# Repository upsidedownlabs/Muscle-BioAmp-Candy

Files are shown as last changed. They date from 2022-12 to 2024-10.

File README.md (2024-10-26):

# Muscle-BioAmp-Candy

 



[]() 
 


A candy size ElectroMyography (EMG) sensor for precise muscle bio-potential signals recording at an affordable cost. It comes with a fixed gain of x2420 and BandPass filter of 72Hz - 720Hz. To record the EMG signals you can use any standalone ADC like ADS1115 or any microcontroller development board with an ADC of your choice like Arduino UNO/Nano.

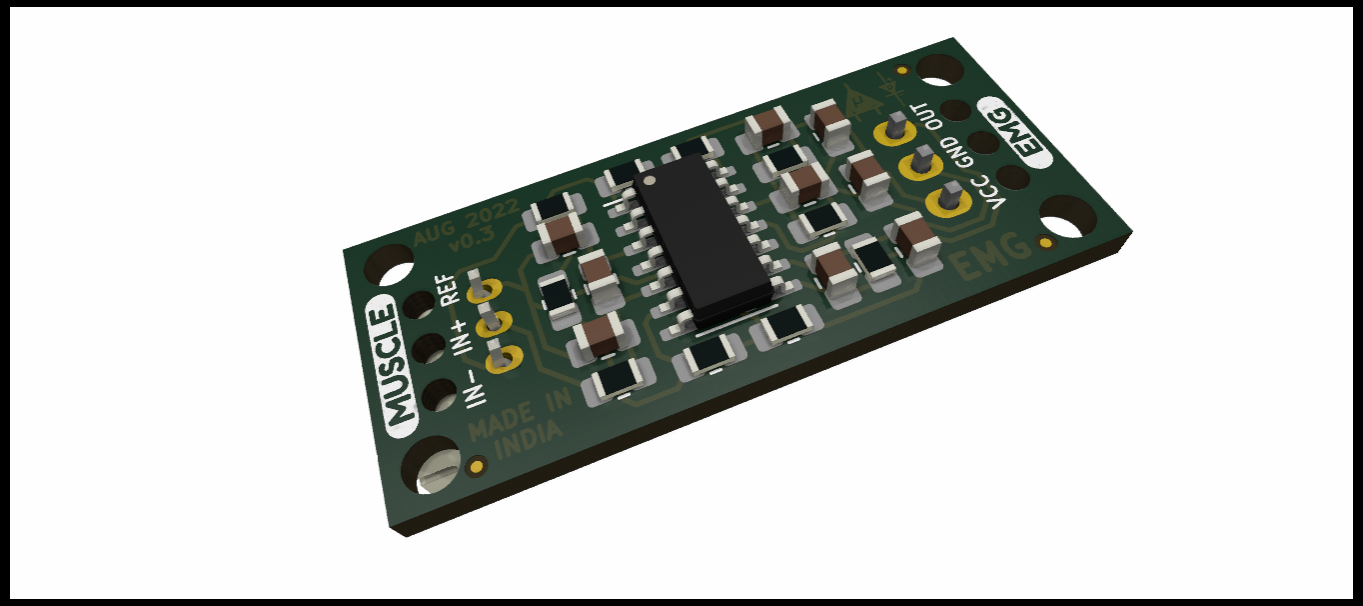
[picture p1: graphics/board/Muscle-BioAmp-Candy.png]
Upside Down Labs - Muscle BioAmp Candy


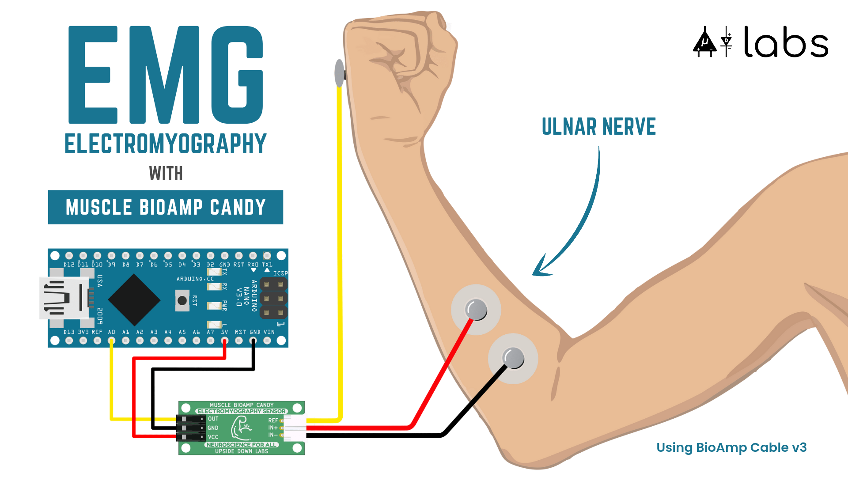
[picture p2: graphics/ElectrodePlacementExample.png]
Upside Down Labs - Muscle BioAmp Candy electrode placement


## Hardware

Muscle BioAmp Candy has been created using KiCad and all the design files can be found under [hardware](hardware/) folder. Images below shows a quick overview of the hardware design.

| PCB Front |  PCB Back |
| :---: | :---: |
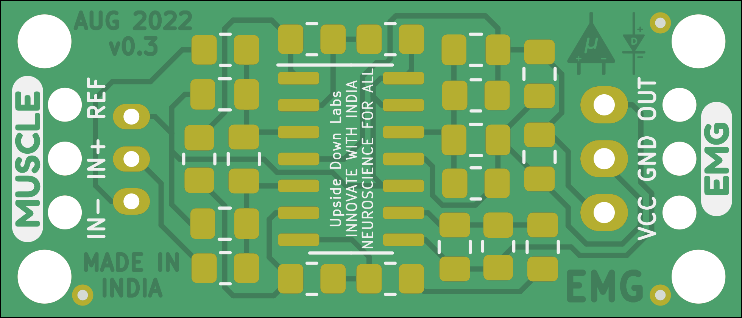
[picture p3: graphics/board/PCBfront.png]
Upside Down Labs Muscle BioAmp Candy front
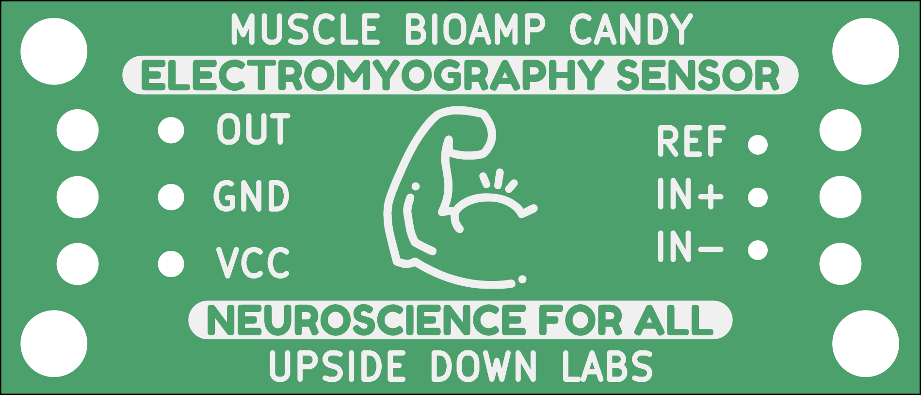
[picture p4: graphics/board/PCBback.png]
Upside Down Labs Muscle BioAmp Candy back
|   |  |

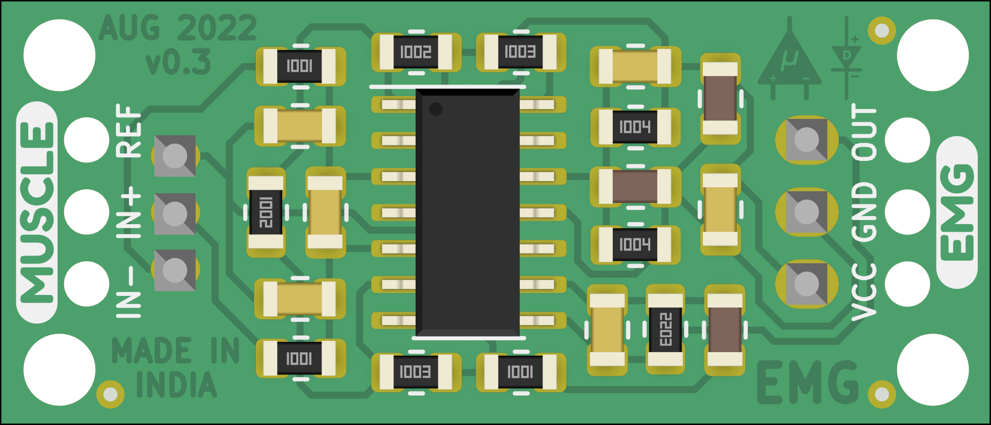
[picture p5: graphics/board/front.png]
Upside Down Labs Muscle BioAmp Candy front annotated


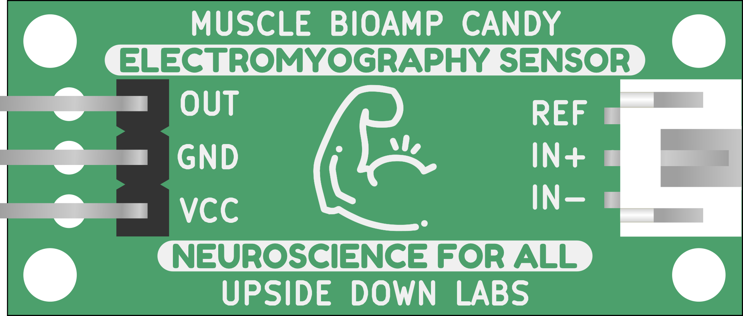
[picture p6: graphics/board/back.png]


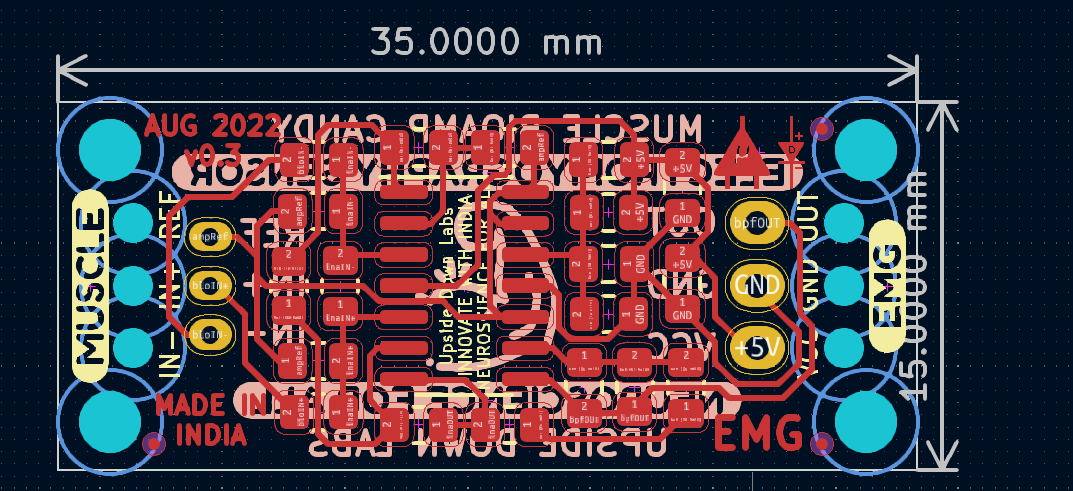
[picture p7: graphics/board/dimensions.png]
Upside Down Labs Muscle BioAmp Candy dimensions


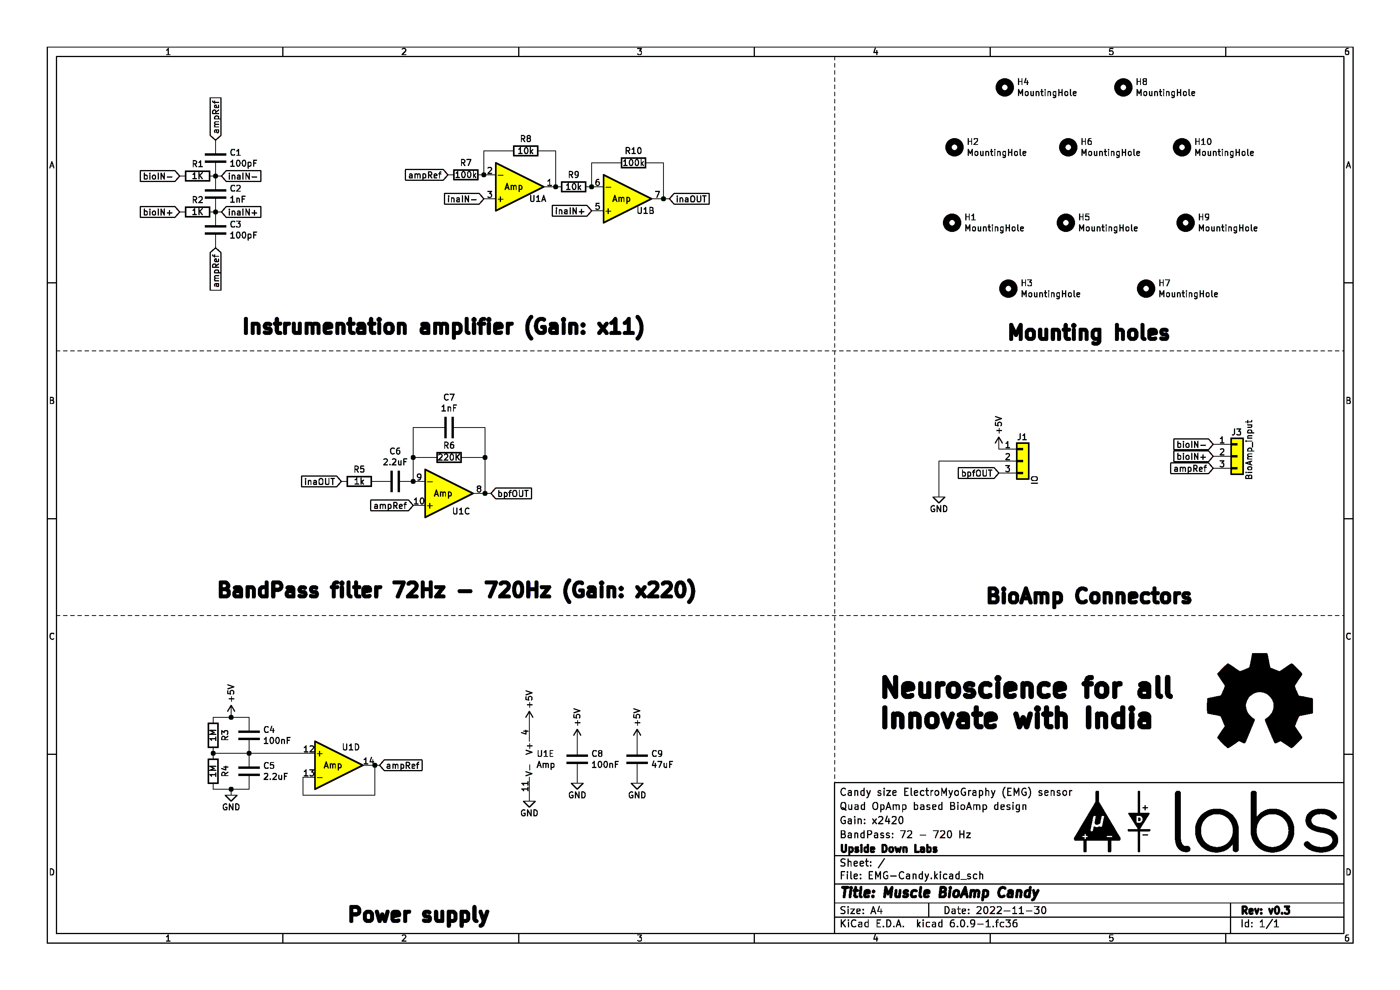
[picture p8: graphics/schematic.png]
Upside Down Labs Muscle BioAmp Candy schematic


## License

| Licenses Facts |  OSHWA Certification |
| :---: | :---: |
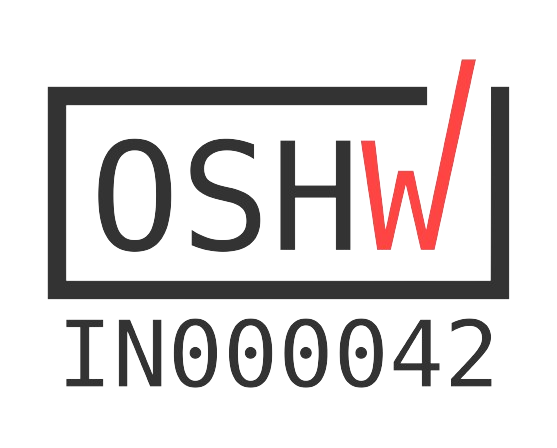
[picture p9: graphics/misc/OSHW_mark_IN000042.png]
Open Source Hardware Certification mark
| <a href="LICENSE.md">Open Source Licenses Facts</a>  |  | 

#### Hardware
CERN Open Hardware License Version 2 - Strongly Reciprocal ([CERN-OHL-S-2.0](https://spdx.org/licenses/CERN-OHL-S-2.0.html)).

#### Software
MIT open source [license](http://opensource.org/licenses/MIT).

#### Documentation:
<br />This work is licensed under a <a rel="license" href="http://creativecommons.org/licenses/by/4.0/">Creative Commons Attribution 4.0 International License</a>.

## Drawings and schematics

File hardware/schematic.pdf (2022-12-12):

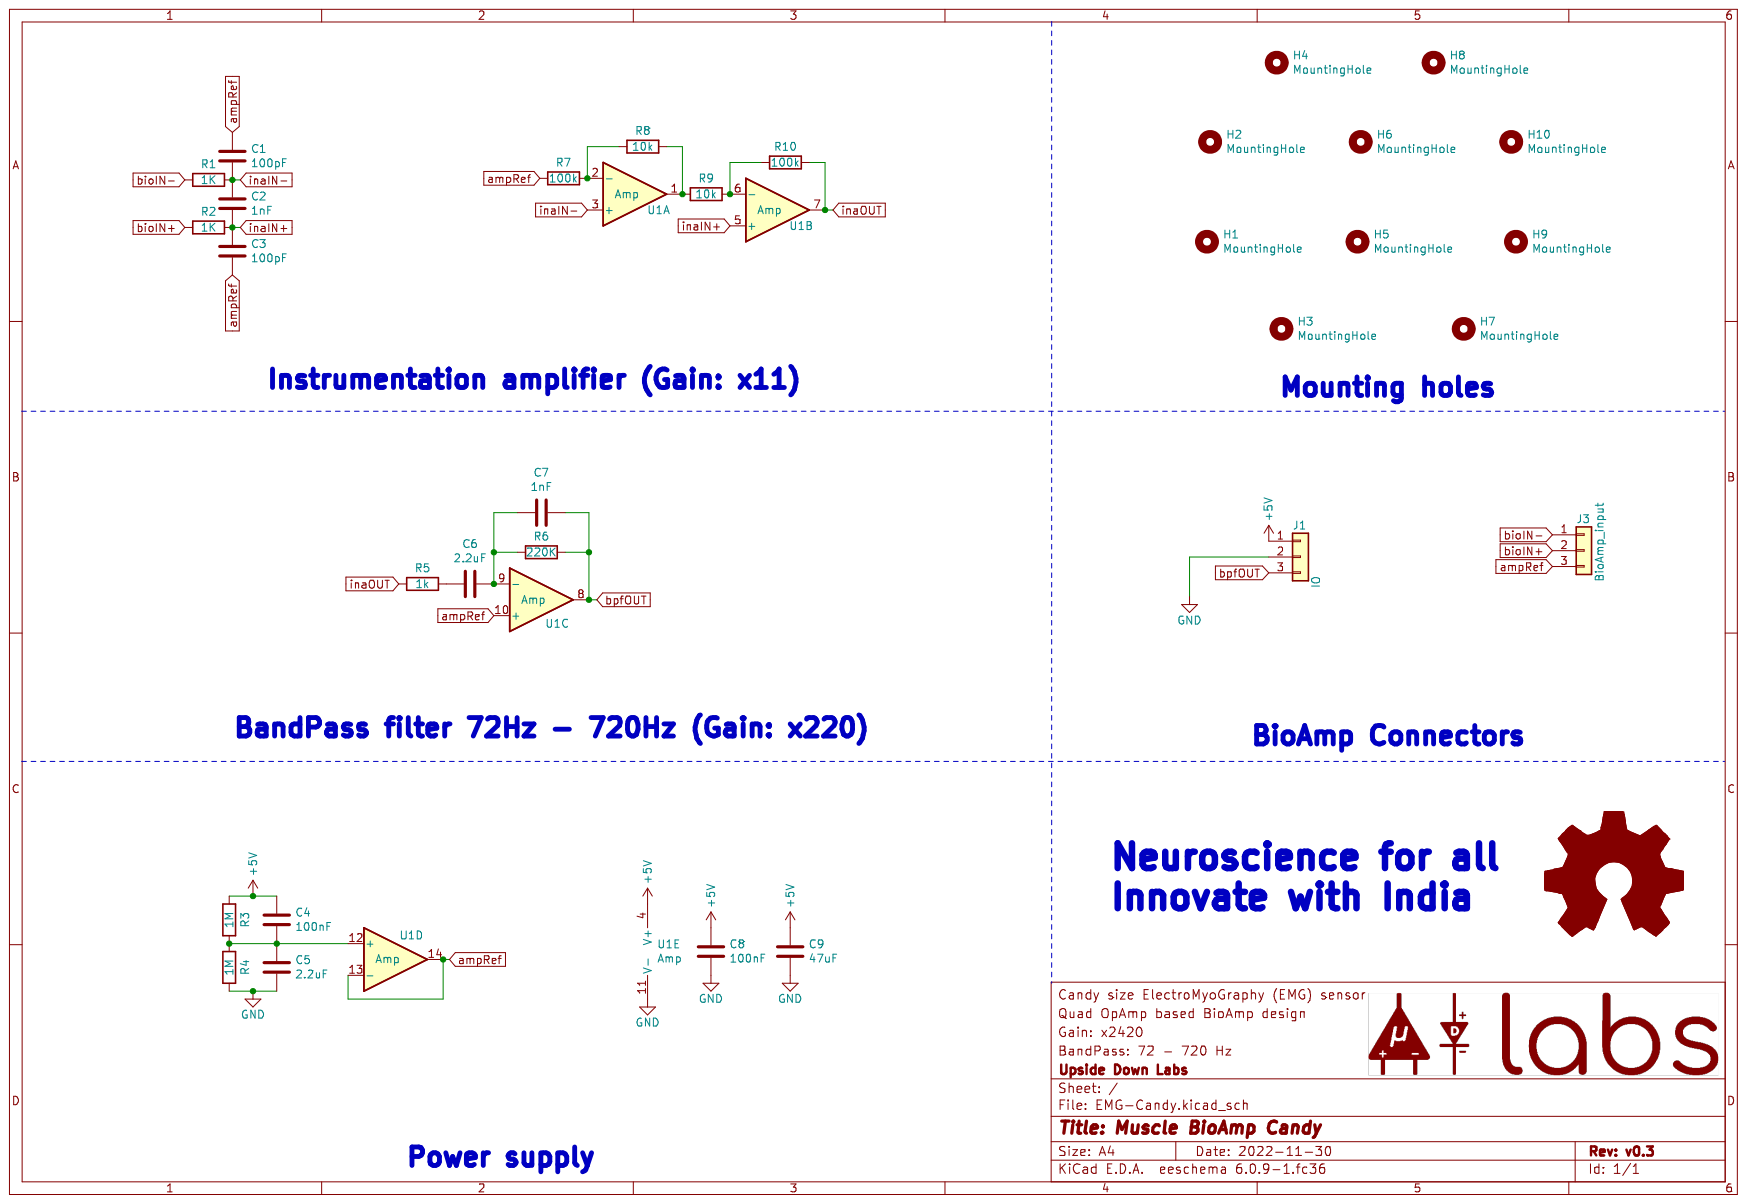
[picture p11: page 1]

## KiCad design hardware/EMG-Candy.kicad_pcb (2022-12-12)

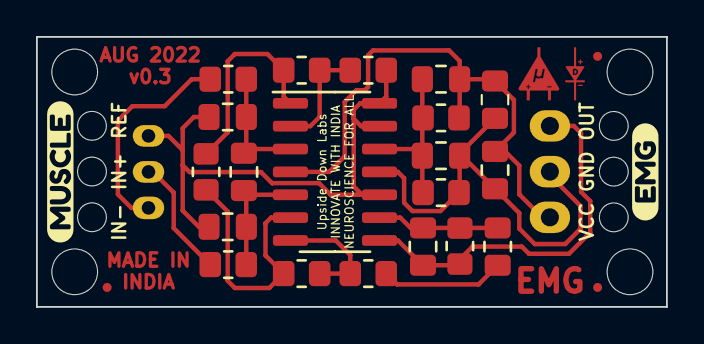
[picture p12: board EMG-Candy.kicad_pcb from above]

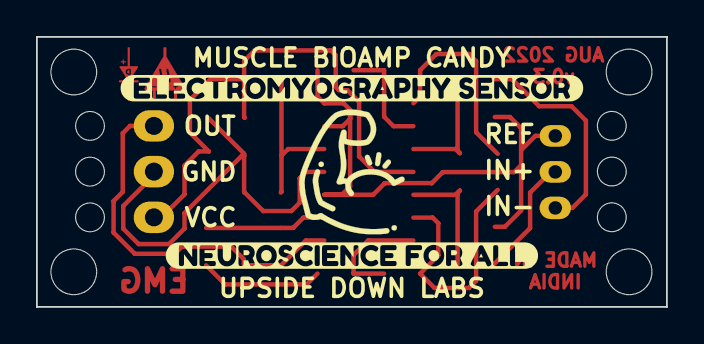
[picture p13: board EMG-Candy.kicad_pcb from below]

Board: 2 copper layers, 35.0 x 15.0 mm, 39 parts (4 on the bottom side), 13 nets.

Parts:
C1, C3: 100pF; C_0805_2012Metric_Pad1.18x1.45mm_HandSolder
C2, C7: 1nF; C_0805_2012Metric_Pad1.18x1.45mm_HandSolder
C4, C8: 100nF; C_0805_2012Metric_Pad1.18x1.45mm_HandSolder
C5, C6: 2.2uF; C_0805_2012Metric_Pad1.18x1.45mm_HandSolder
C9: 47uF; C_0805_2012Metric_Pad1.18x1.45mm_HandSolder
F1**, F2**, F3**: Fiducial_0.5mm_Mask1mm
H1, H2, H3, H4, H5, H6, H7, H8, H9, H10: MountingHole; MountingHole_2.1mm
J1: IO; PinHeader_1x03_P2.54mm_Horizontal
J3: BioAmp_input; JST_PH_S3B-PH-K_1x03_P2.00mm_Horizontal
R1, R2: 1K; R_0805_2012Metric_Pad1.20x1.40mm_HandSolder
R3, R4: 1M; R_0805_2012Metric_Pad1.20x1.40mm_HandSolder
R5: 1k; R_0805_2012Metric_Pad1.20x1.40mm_HandSolder
R6: 220K; R_0805_2012Metric_Pad1.20x1.40mm_HandSolder
R7, R10: 100k; R_0805_2012Metric_Pad1.20x1.40mm_HandSolder
R8, R9: 10k; R_0805_2012Metric_Pad1.20x1.40mm_HandSolder
U1: Amp; SOIC-14_3.9x8.7mm_P1.27mm
kibuzzard-62E8CB67: G***; kibuzzard-62E8CB67
kibuzzard-626BB171: G***; kibuzzard-626BB171
kibuzzard-626FA17E: G***; kibuzzard-626FA17E
kibuzzard-626FA157: G***; kibuzzard-626FA157

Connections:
+5V: C4.2, C8.2, C9.2, R3.2, U1.4 (V+)
GND: C5.1, C8.1, C9.1, R4.1, U1.11 (V-)
unnamed: C4.1, C5.2, R3.1, R4.2, U1.12 (+)
unnamed: C6.1, R5.1
unnamed: C6.2, C7.1, R6.2, U1.9 (-)
unnamed: R7.1, R8.2, U1.2 (-)
unnamed: R8.1, R9.2, U1.1
unnamed: R9.1, R10.2, U1.6 (-)
ampRef: C1.2, C3.1, R7.2, U1.10 (+), U1.13 (-), U1.14
bpfOUT: C7.2, R6.1, U1.8
inaIN+: C2.1, C3.2, R2.1, U1.5 (+)
inaIN-: C1.1, C2.2, R1.1, U1.3 (+)
inaOUT: R5.2, R10.1, U1.7

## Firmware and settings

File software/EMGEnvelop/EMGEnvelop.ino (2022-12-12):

// EMG Envelop - Muscle BioAmp Candy
// https://github.com/upsidedownlabs/Muscle-BioAmp-Candy

// Upside Down Labs invests time and resources providing this open source code,
// please support Upside Down Labs and open-source hardware by purchasing
// products from Upside Down Labs!

// Copyright (c) 2021-2022 Upside Down Labs - contact@upsidedownlabs.tech

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
#define SAMPLE_RATE 500
#define BAUD_RATE 115200
#define INPUT_PIN A0
#define BUFFER_SIZE 128

int circular_buffer[BUFFER_SIZE];
int data_index, sum;

void setup() {
	// Serial connection begin
	Serial.begin(BAUD_RATE);
}

void loop() {
	// Calculate elapsed time
	static unsigned long past = 0;
	unsigned long present = micros();
	unsigned long interval = present - past;
	past = present;

	// Run timer
	static long timer = 0;
	timer -= interval;

	// Sample and get envelop
	if(timer < 0) {
		timer += 1000000 / SAMPLE_RATE;
		int sensor_value = analogRead(INPUT_PIN);
		int signal = EMGFilter(sensor_value);
		int envelop = getEnvelop(abs(signal));
		Serial.print(signal);
		Serial.print(",");
		Serial.println(envelop);
	}
}

// Envelop detection algorithm
int getEnvelop(int abs_emg){
	sum -= circular_buffer[data_index];
	sum += abs_emg;
	circular_buffer[data_index] = abs_emg;
	data_index = (data_index + 1) % BUFFER_SIZE;
	return (sum/BUFFER_SIZE) * 2;
}

// Band-Pass Butterworth IIR digital filter, generated using filter_gen.py.
// Sampling rate: 500.0 Hz, frequency: [74.5, 149.5] Hz.
// Filter is order 4, implemented as second-order sections (biquads).
// Reference: 
// https://docs.scipy.org/doc/scipy/reference/generated/scipy.signal.butter.html
// https://courses.ideate.cmu.edu/16-223/f2020/Arduino/FilterDemos/filter_gen.py
float EMGFilter(float input)
{
  float output = input;
  {
    static float z1, z2; // filter section state
    float x = output - 0.05159732*z1 - 0.36347401*z2;
    output = 0.01856301*x + 0.03712602*z1 + 0.01856301*z2;
    z2 = z1;
    z1 = x;
  }
  {
    static float z1, z2; // filter section state
    float x = output - -0.53945795*z1 - 0.39764934*z2;
    output = 1.00000000*x + -2.00000000*z1 + 1.00000000*z2;
    z2 = z1;
    z1 = x;
  }
  {
    static float z1, z2; // filter section state
    float x = output - 0.47319594*z1 - 0.70744137*z2;
    output = 1.00000000*x + 2.00000000*z1 + 1.00000000*z2;
    z2 = z1;
    z1 = x;
  }
  {
    static float z1, z2; // filter section state
    float x = output - -1.00211112*z1 - 0.74520226*z2;
    output = 1.00000000*x + -2.00000000*z1 + 1.00000000*z2;
    z2 = z1;
    z1 = x;
  }
  return output;
}

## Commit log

2022-12-12 Updare hardware files
    [EMG-Candy.kicad_pcb, EMG-Candy.kicad_sch]
2022-12-12 Add interactive BOM

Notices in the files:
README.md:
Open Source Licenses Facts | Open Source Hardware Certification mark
